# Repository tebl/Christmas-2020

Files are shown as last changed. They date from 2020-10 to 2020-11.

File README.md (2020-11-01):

# Christmas 2020
I wanted to do this project last year, but my health deteriorated and so the big Christmas 2019 project became the big Christmas 2020 project instead. 2020, if anything, provided plenty of time for sitting around the house thinking up how to make a blinking LED christmas tree with an Arduino Nano built into it! I even got around to adding a small video of it in action on [YouTube](https://www.youtube.com/watch?v=C256A0oTeUM)!

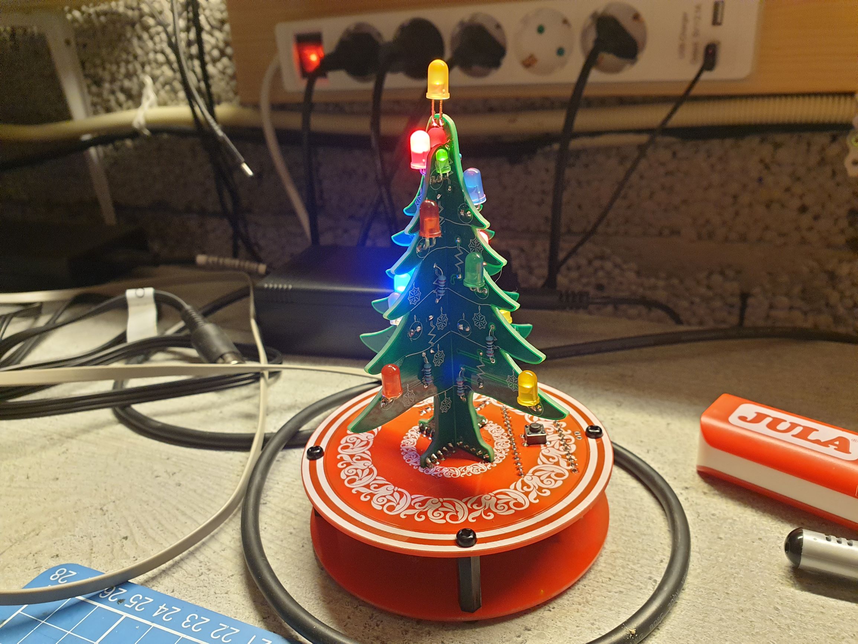
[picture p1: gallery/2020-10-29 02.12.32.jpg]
Christmas tree


The project is composed of three PCB designs, parts A/B are the actual tree and have been made so that they slot into eachother. Part C is the base, it holds the Arduino Nano and a couple of shift registers in addition to a switch that is used in order to toggle the various modes (I added a second Part C board to the bottom to add a little more weight).

As with any Christmas tree, you can decorate it with any LEDs though you might need to adjust the resistor values accordingly so that some of them aren't extremely bright (when in doubt, try them on a breadboard first). Alternatively - you could choose to skip the whole decorating step and put some string at the top and hang it from your tree (you will need to use some wire on the bottom to keep it from falling apart).

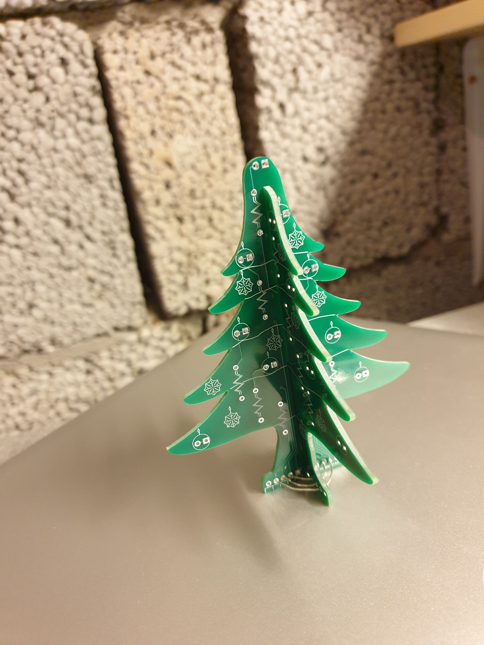
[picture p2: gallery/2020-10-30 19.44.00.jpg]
Bare christmas tree


## Building it
Start by examining all three PCBs, assuming you already have those handy - refer to the BOM below if you're wondering what parts to order from your favourite electronics boutique. Both of the A/B, the two tree parts should have a christmas bauble (at least I think that is the correct English translation of the round glass decorations) specifying both the part name (A or B) and wether you're looking at the front or the back. The latter details, the front and back bit, matters because this is the orientation it needs to be in when you want to slot it into the base (part C).

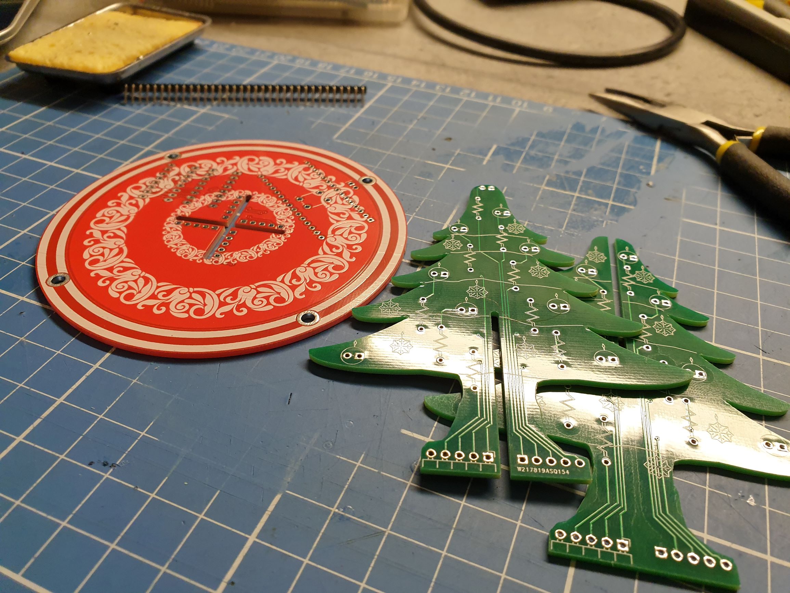
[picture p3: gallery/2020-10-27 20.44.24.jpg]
PCBs


Because I wanted something that looked good without any components, parts A/B will look different from the standard markings used for LEDs and resistors you would expect to encounter any other time of the year. The baubles with the two holes are for LEDs, you can solder them straight on or aim them upwards if you'd like to - feel free to use those weird LEDs you got as a gift (it's your tree after all) - the important bit is that the **square pad** is for the negative leg of the LED (the **shorter** one). The squiggly lines are for the resistors, you need to pick values that work with your LEDs, so test them in a breadboard first in order to figure out which value to use (or just put 100 Ohm for the dim ones, 330 for the normal LEDs and something like 1K for those bright ones like the blue). Try installing components so that every side gets something, at least that's what my parents always instruct me to do on the big plastic tree.

Parts A/B are attached to the base using right-angle pin headers, take care that you match the orientation to the corresponding parts on part C. While on the subject of part C, the only important part here is that you'll probably need to solder the switch into place before putting in the Arduino Nano (unless you'll be using female header pins so that you can remove it later). The rest of the components (including the Nano) will be installed on the underside of part C.

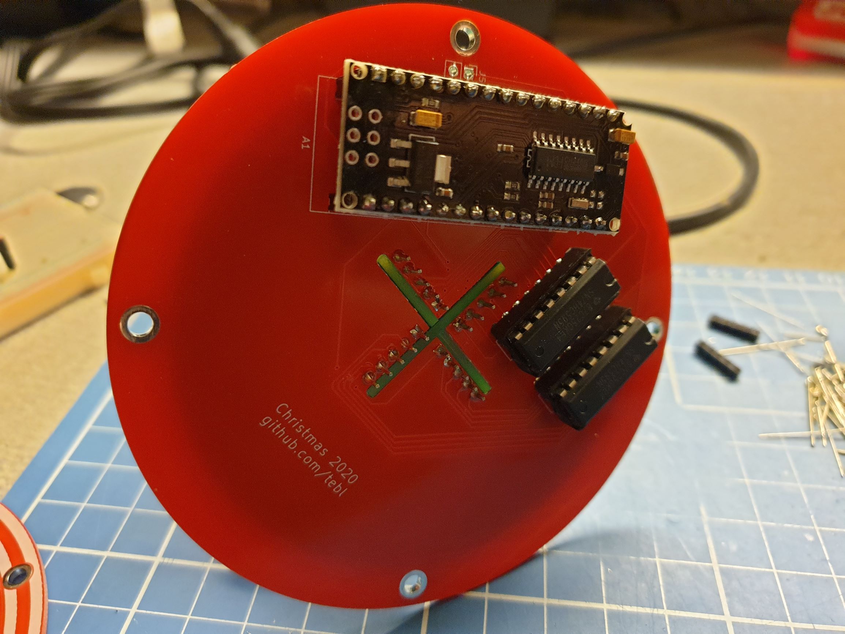
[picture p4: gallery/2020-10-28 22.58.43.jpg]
PCB component side


Given that there are components on the underside of the base, you'll need to add some M3 hex spacers to it so that it won't scrape against the table - if you have an extra part C PCB I recommend putting it on the bottom as well so that it doesn't get knocked around so easily.

## BOM
The BOM, or bill of manufacturing, is a list of the components used when constructing the complete christmas tree. Note that since you can substitute the LEDs/resistors you want to use - the following may be more of a suggestion though you'd need all of it in order to make everything blink. Most of these components should be easily obtainable through your favourite local electronics components store. Right-angle pin headers are usually sold in breakable strips with 40 pins, so just break off 5 pin segments where needed.

| Reference | Item | Count |
| --- | --- | ----- |
| Christmas A  | Fabricate using Gerber files ([order](https://www.pcbway.com/project/shareproject/Christmas_2020__part_A_.html)) | 1 |
| D1-D9 | LED (3mm or 5mm, colour as wanted) | 9 |
| R1-R9 | 220, 330 or 1k ohm resistor * | 9 |
| J1,J2 | 1x5-pin right-angle header | 2 |
| Christmas B  | Fabricate using Gerber files ([order](https://www.pcbway.com/project/shareproject/Christmas_2020__part_B_.html)) | 1 |
| D2-D9 | LED (3mm or 5mm, colour as wanted) | 8 |
| R2-R9 | 220, 330 or 1k ohm resistor * | 8 |
| J1,J2 | 1x5-pin right-angle header | 2 |
| Christmas C  | Fabricate using Gerber files ([order](https://www.pcbway.com/project/shareproject/Christmas_2020__part_C_.html)) | 1 |
| SW1 | SPST momentary push button | 1 |
| A1 | Arduino Nano | 1 |
| U1,U2 | 74HC595 (DIP-16) | 2 |
| | M3 nylon hex standoffs with screws | 4 |

*) Use resistors with values that would correspond to the LED you installed, use higher resistrance the brighter the LED (especially the blue ones). If a soldered in LED is too dim, install a lower value on the back as well in order to lower the resistance going to it.

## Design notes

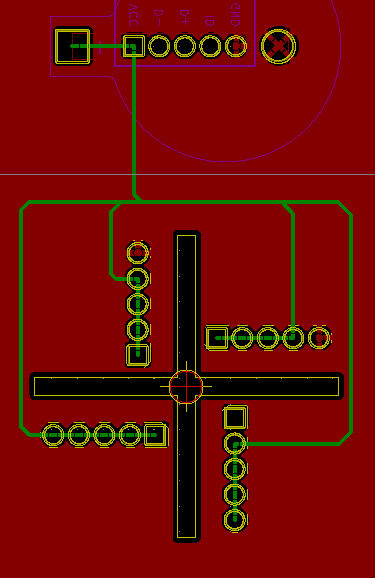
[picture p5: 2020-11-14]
gallery/Screenshot 2020-11-14 233453.png

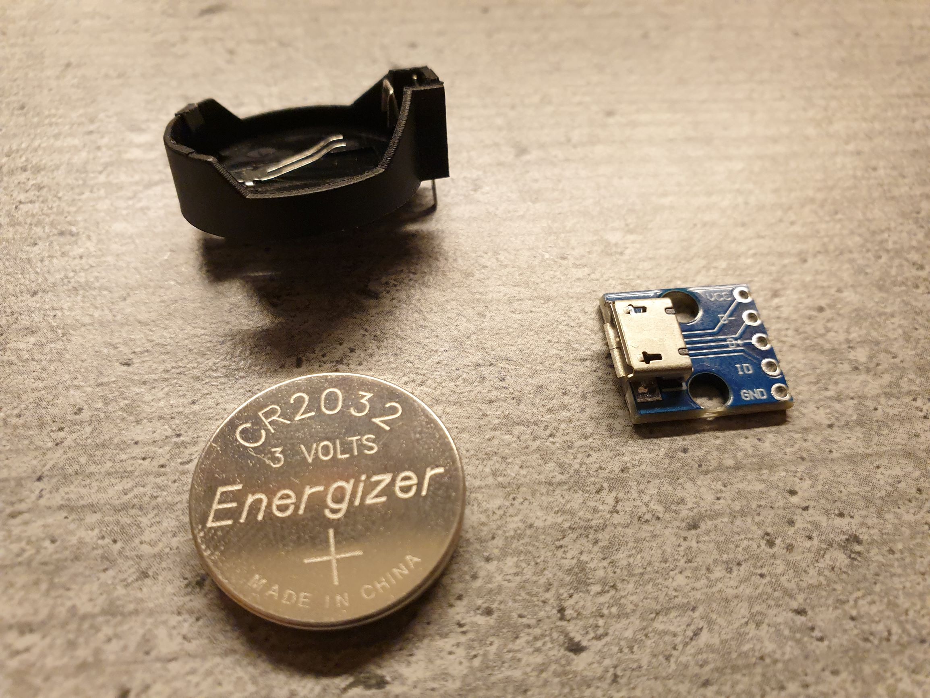
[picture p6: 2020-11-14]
gallery/2020-11-14 23.36.01.jpg

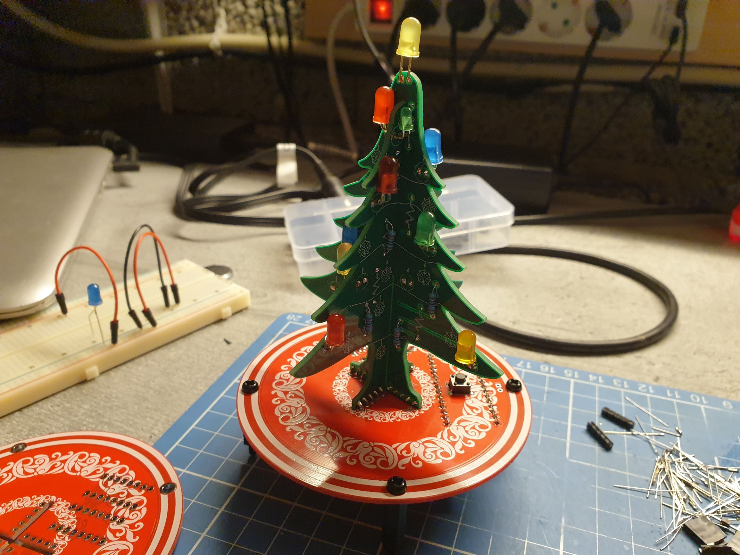
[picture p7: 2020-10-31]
gallery/2020-10-28 23.00.49.jpg

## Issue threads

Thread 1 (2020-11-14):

Request for an alternate version

Treearecool, 2020-11-14:
Hello,

I really like how the tree looks and works, but i am reluctant to create multiple of them to gift them out to my friends and family. Is it possible that you can create a battery powered version of the Part C board, perhaps with a CR2032-BS-5-1 connector, that simply powers the tree, without it blinking? It could keep costs down and would still look good as a gift.

Thanks!

tebl, 2020-11-14:
If you already have part C, then you could do that with a few wires though I realize that might scare most that aren't used to DIY projects (see https://github.com/tebl/Christmas-2020/raw/main/gallery/Screenshot%202020-11-14%20233453.png for example). I threw together a part C2 like you described - could not use the part you specified as I do not have it, also it is meant to be installed vertically instead of flat on a board. Did an option for the generic black flat chinese CR2032 holder instead as well as a MicroUSB breakout module (see https://github.com/tebl/Christmas-2020/raw/main/gallery/2020-11-14%2023.36.01.jpg for picture).

Treearecool, 2020-11-15:
Thank You Very Much.

Closed 2020-11-15.

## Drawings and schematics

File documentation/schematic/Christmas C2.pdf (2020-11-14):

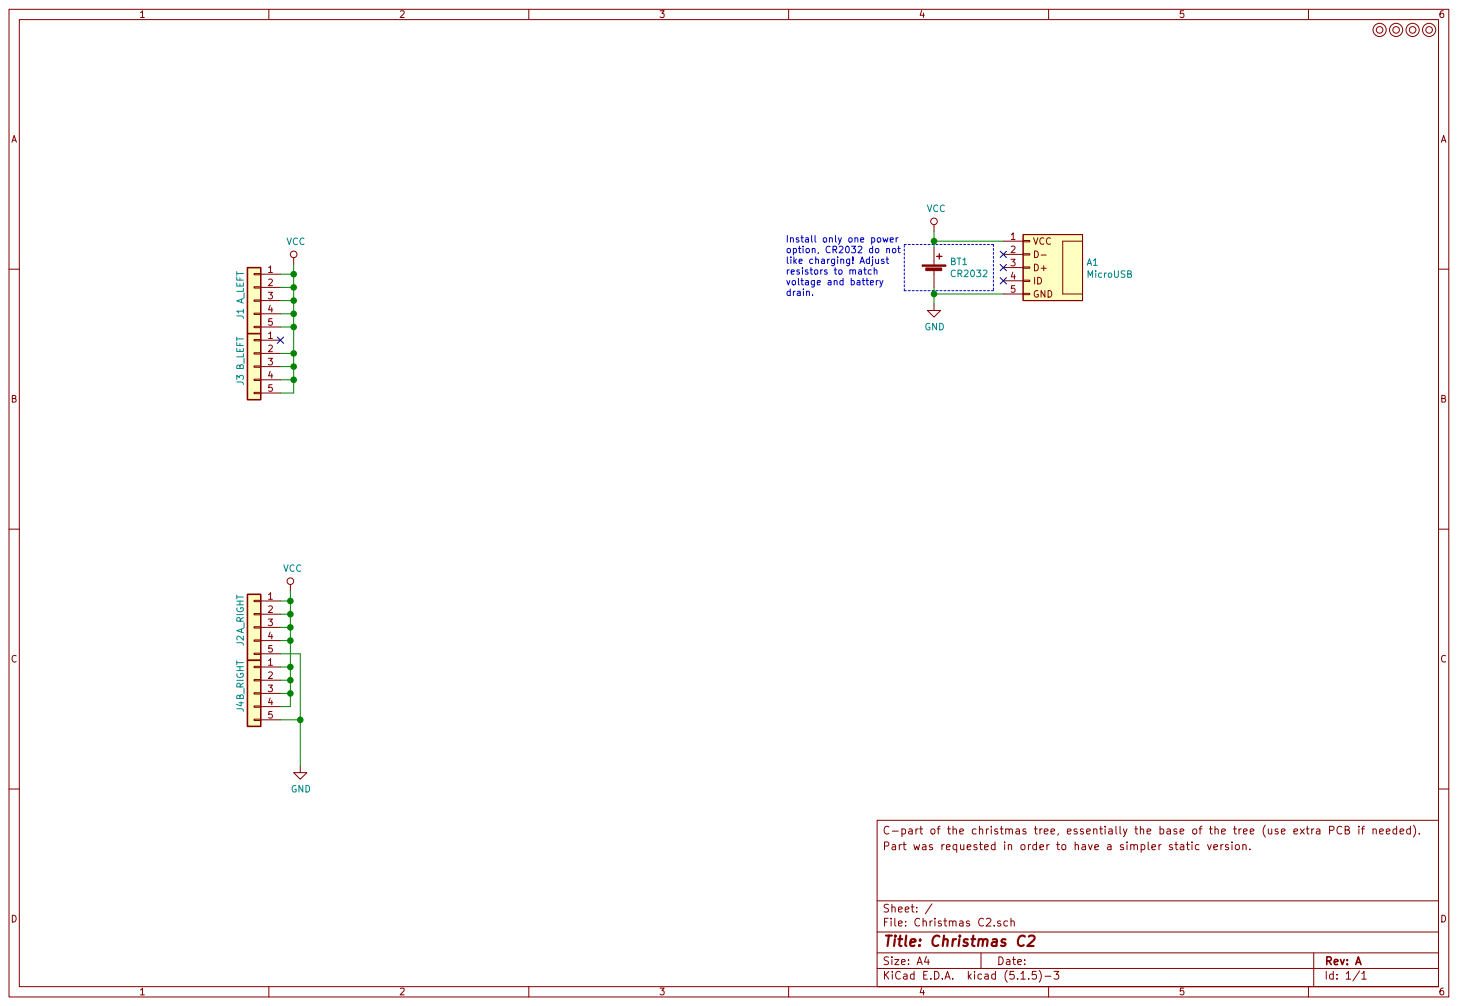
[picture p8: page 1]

Install only one power
option, CR2032 do not
like charging! Adjust resistors to match voltage and battery drain.

C-part of the christmas tree, essentially the base of the tree (use extra PCB if needed).
File: Christmas C2.sch Sheet: / Part was requested in order to have a simpler static version.

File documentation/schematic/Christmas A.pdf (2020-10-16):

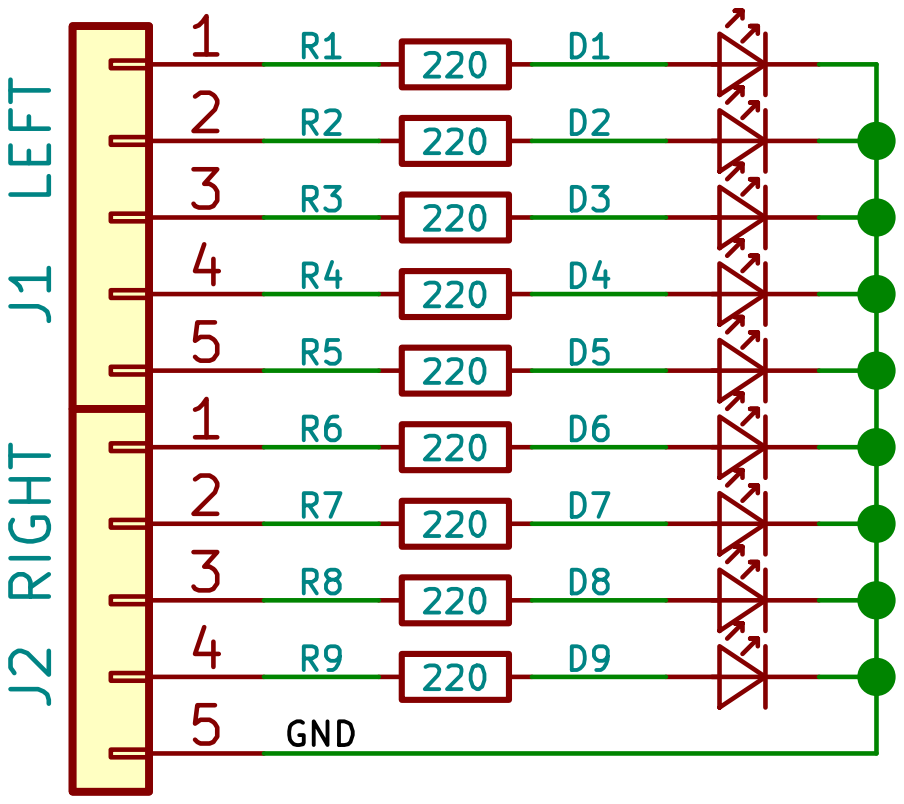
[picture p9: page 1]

File: Christmas A.sch Sheet: / Slot into B-side before soldering star into place. A-side of the christmas tree.

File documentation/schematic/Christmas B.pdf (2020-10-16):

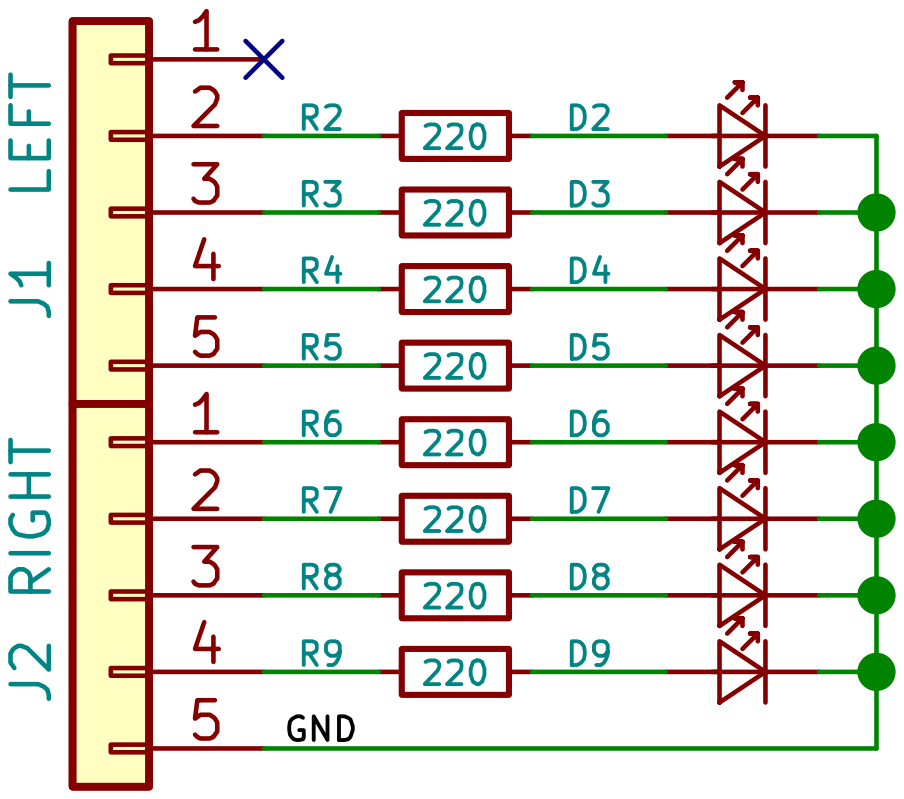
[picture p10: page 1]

File: Christmas B.sch Sheet: / Slot into A-side before soldering star into place. B-side of the christmas tree.

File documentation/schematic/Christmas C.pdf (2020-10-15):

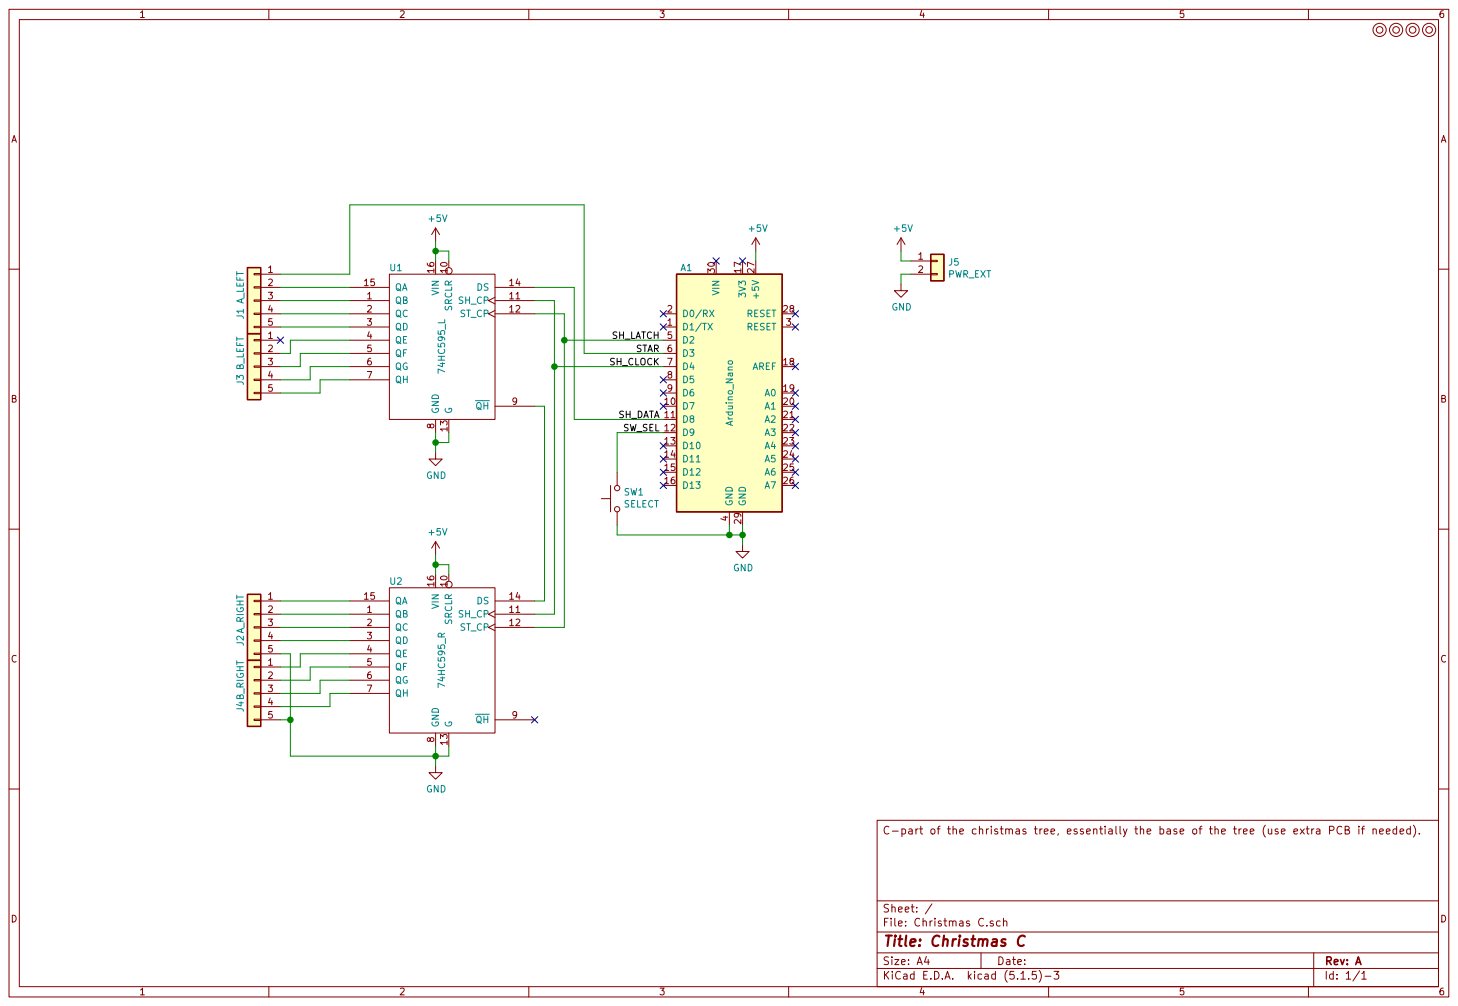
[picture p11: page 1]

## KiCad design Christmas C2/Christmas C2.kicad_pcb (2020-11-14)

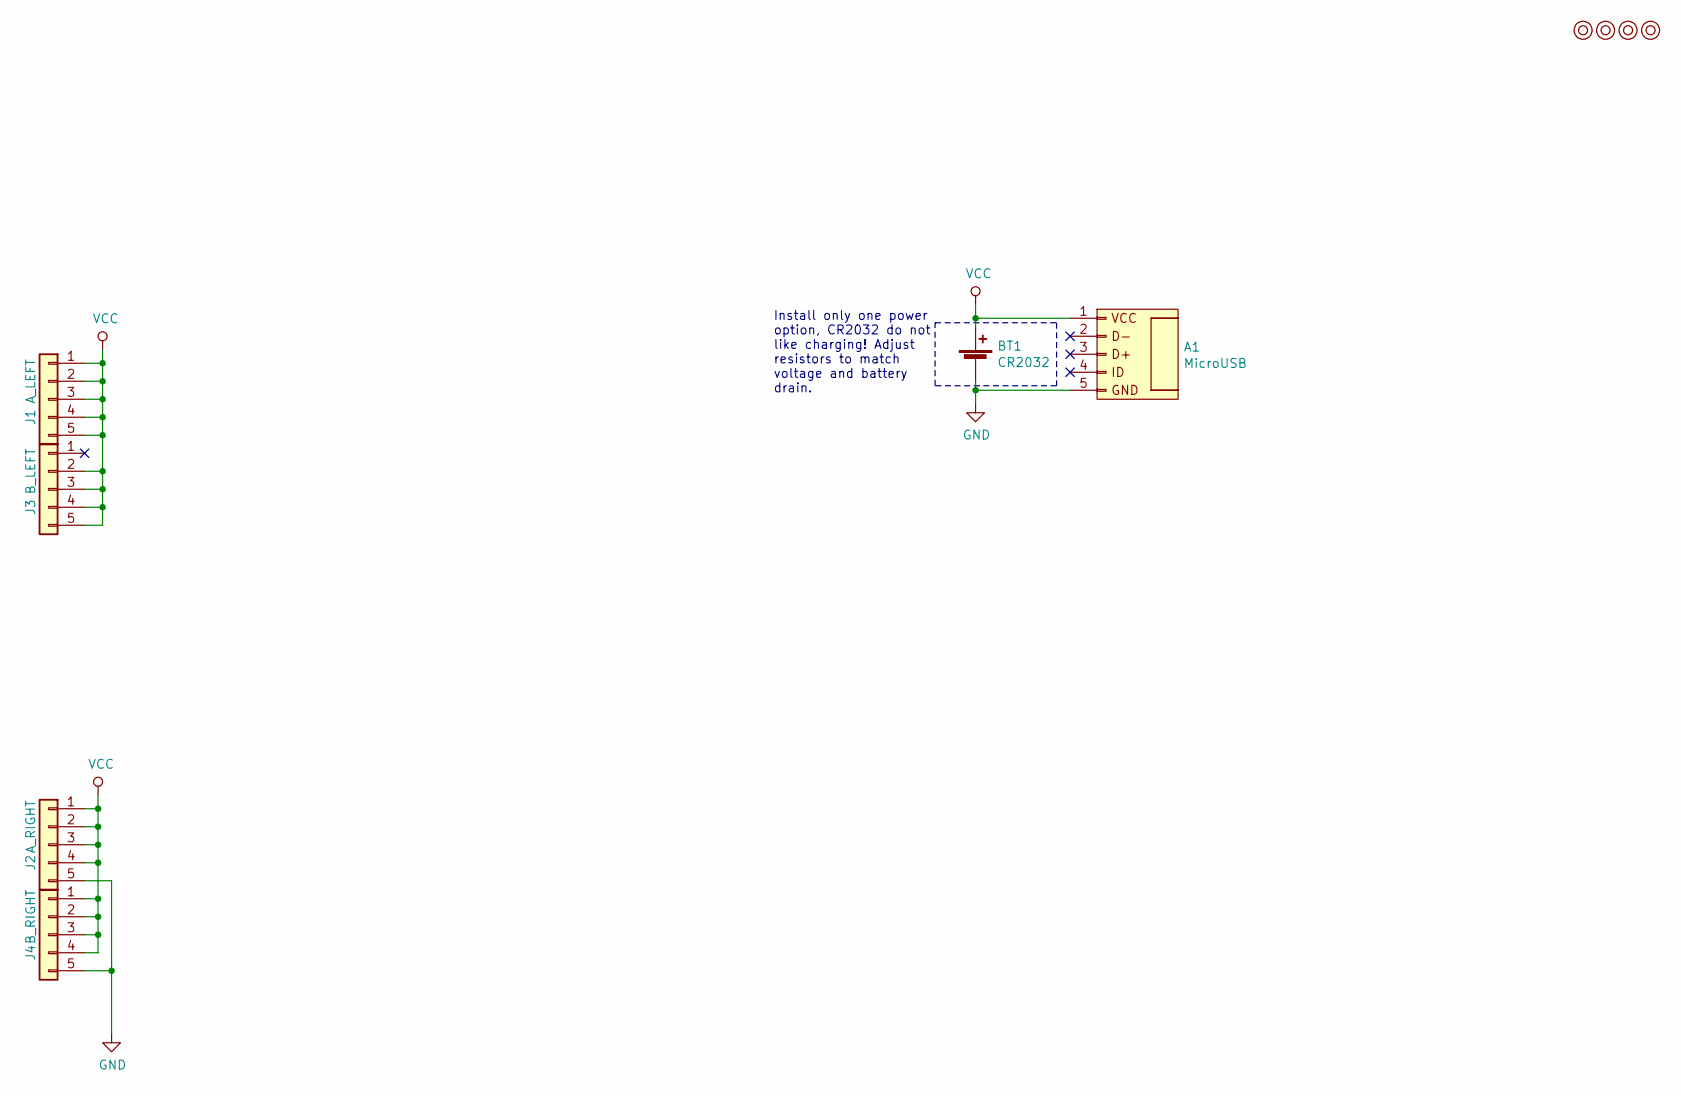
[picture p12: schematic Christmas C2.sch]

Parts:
A1: MicroUSB; microusb_breakout
BT1: CR2032; Keystone_103_1x20mm-CoinCell
J1: A_LEFT; conn_base
J2: A_RIGHT; conn_base
J3: B_LEFT; conn_base
J4: B_RIGHT; conn_base
M1, M2, M3, M4: Mounting; M3

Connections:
GND: A1.5 (GND), BT1.2 (-), J2.5, J4.5
VCC: A1.1 (VCC), BT1.1 (+), J1.1, J1.2, J1.3, J1.4, J1.5, J2.1, J2.2, J2.3, J2.4, J3.2, J3.3, J3.4, J3.5, J4.1, J4.2, J4.3, J4.4

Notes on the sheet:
Install only one power option, CR2032 do not like charging! Adjust resistors to match voltage and battery drain.

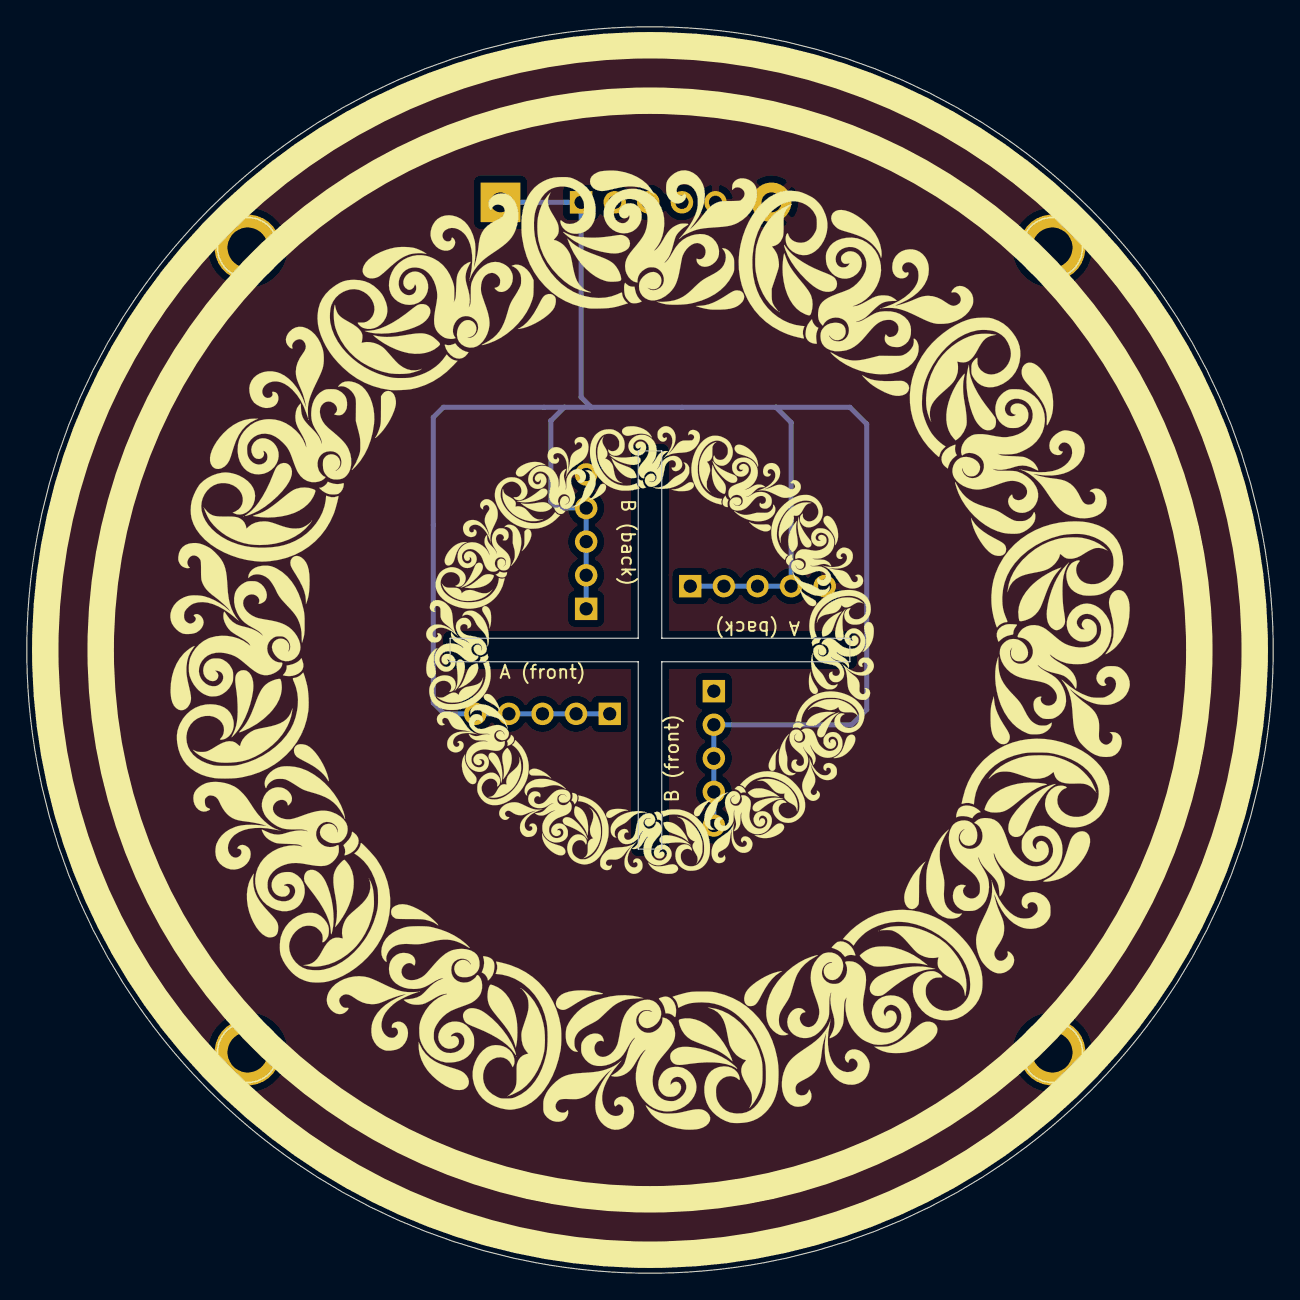
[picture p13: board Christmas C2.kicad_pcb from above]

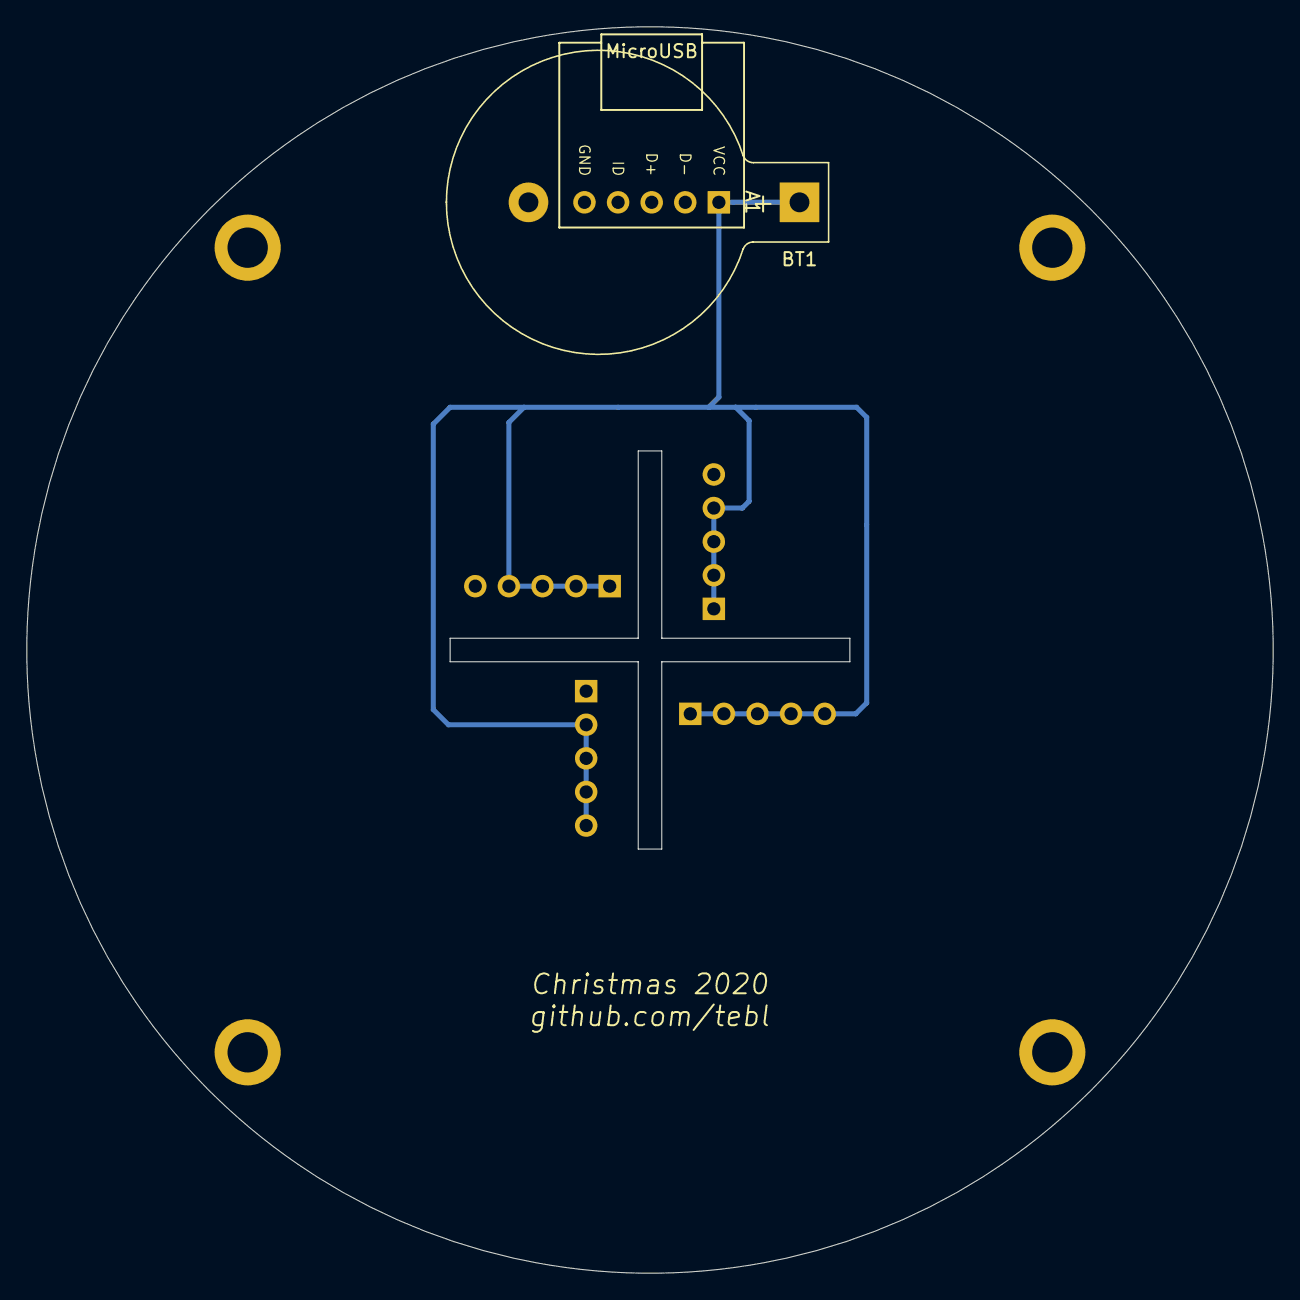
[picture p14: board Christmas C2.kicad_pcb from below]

Board: 2 copper layers, 94.2 x 94.2 mm, 10 parts (2 on the bottom side), 2 nets.

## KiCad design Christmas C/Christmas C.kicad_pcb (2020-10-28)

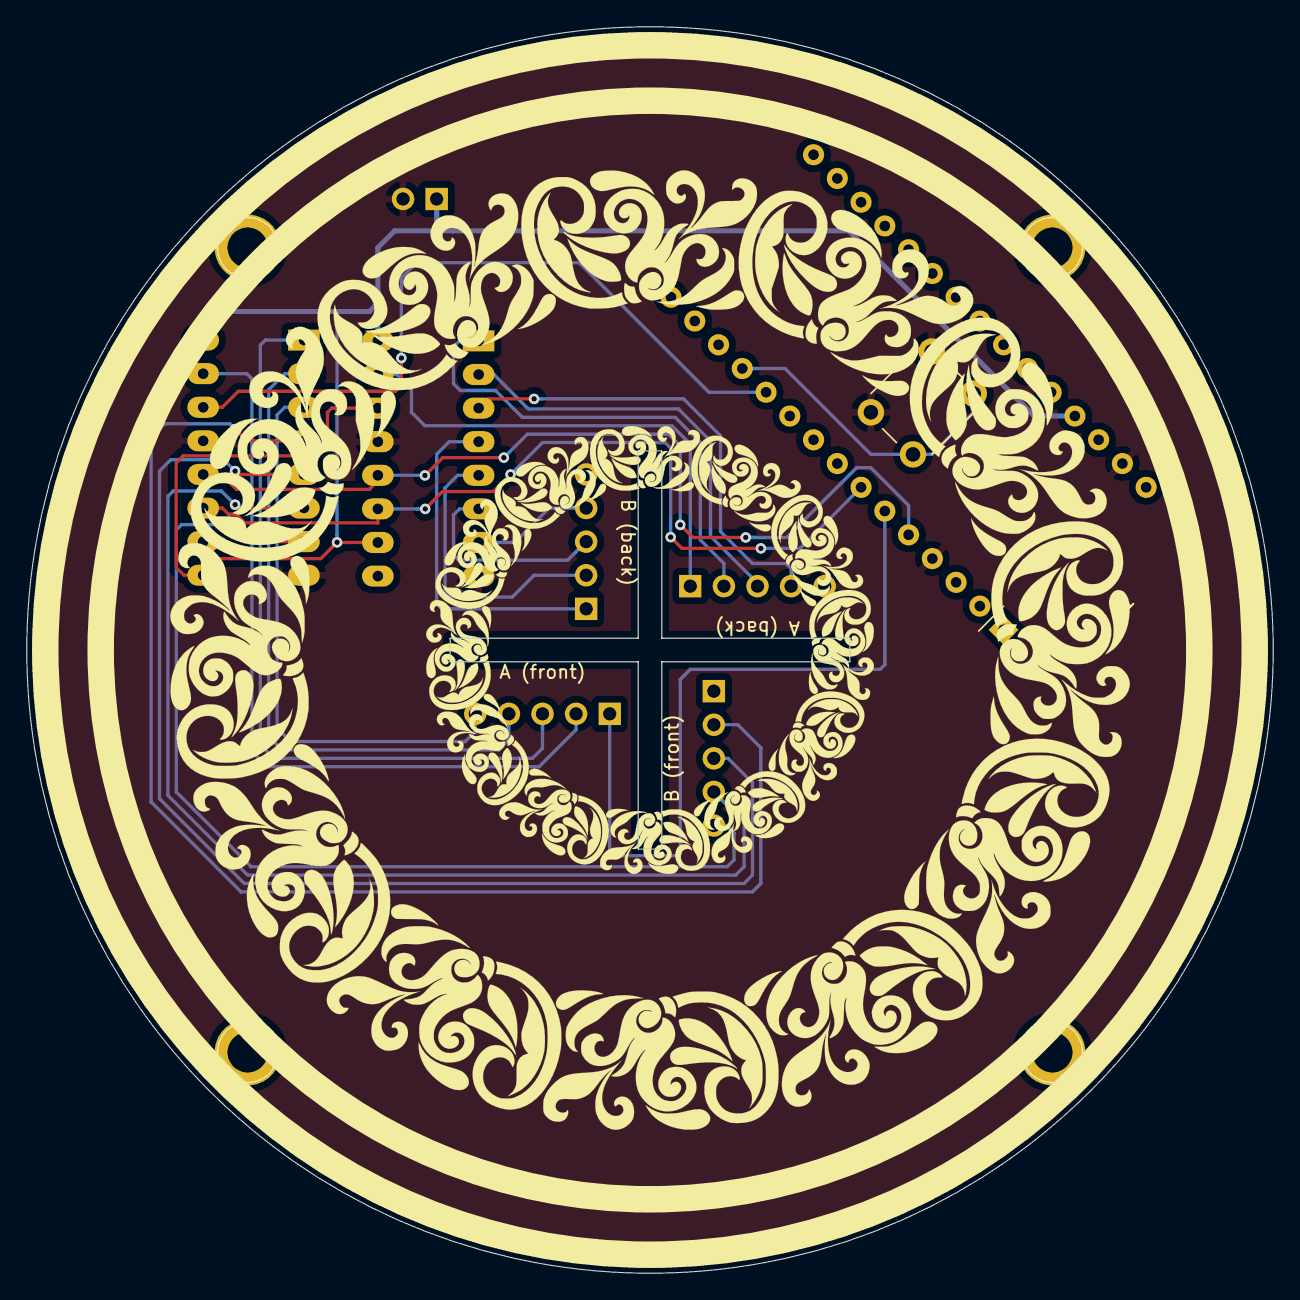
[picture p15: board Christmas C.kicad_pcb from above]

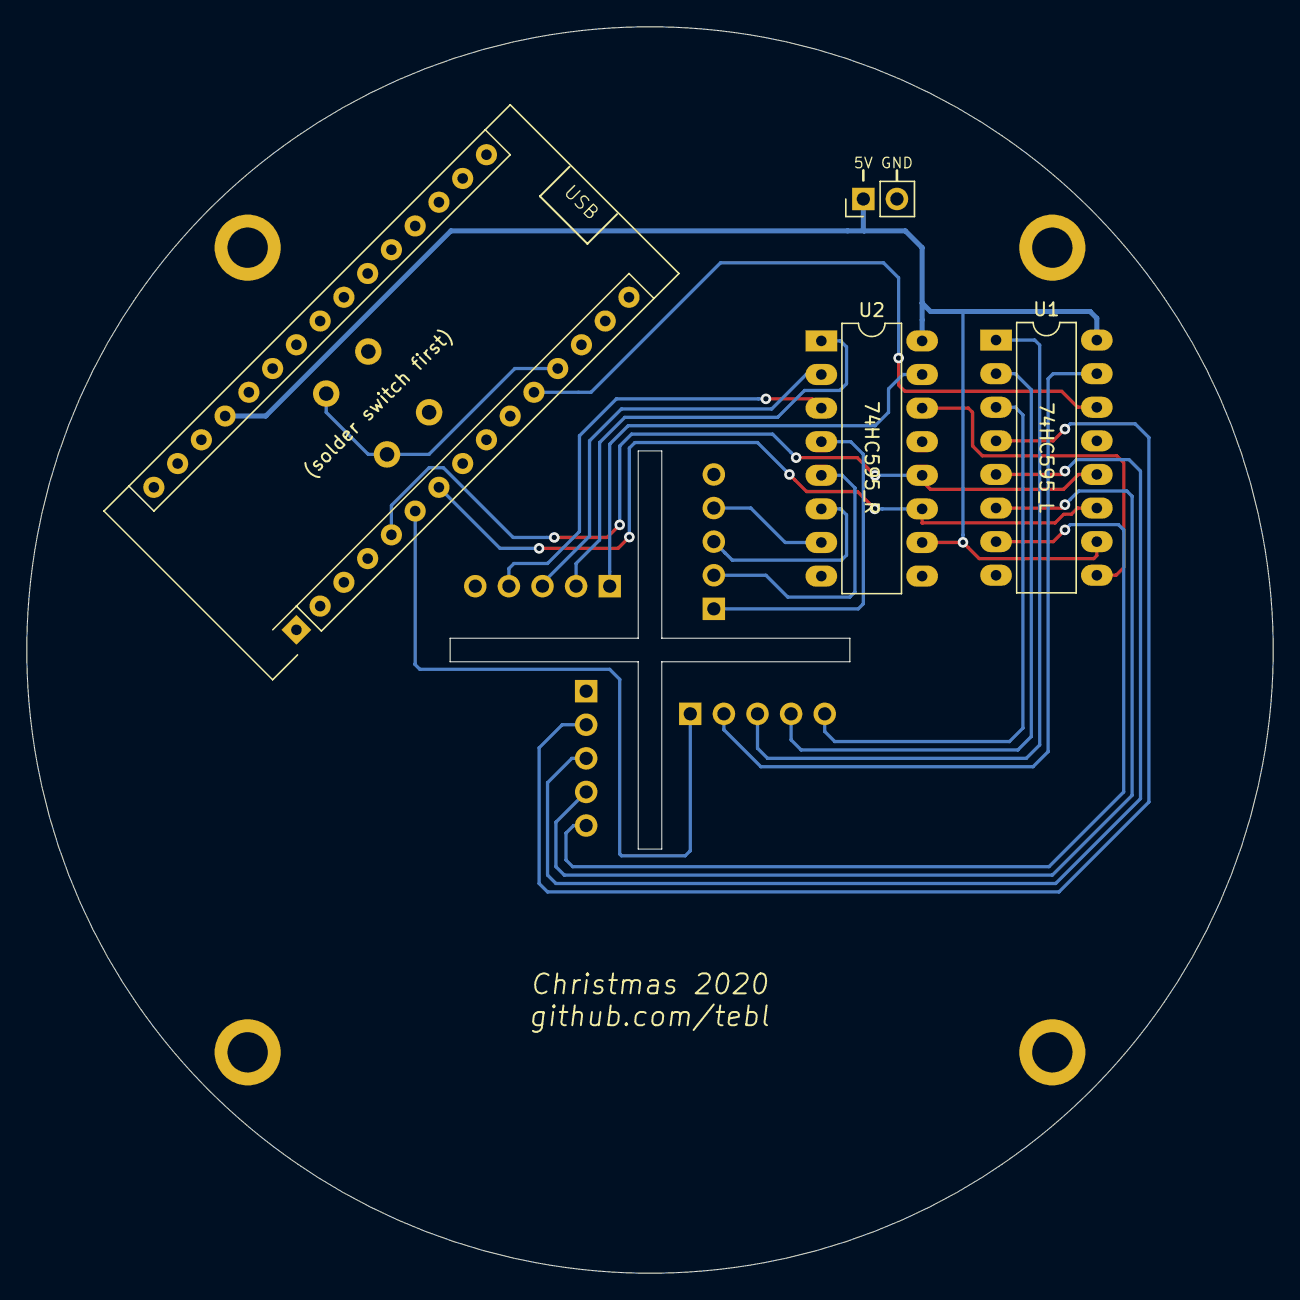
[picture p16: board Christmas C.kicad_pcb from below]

Board: 2 copper layers, 94.2 x 94.2 mm, 13 parts (4 on the bottom side), 24 nets.

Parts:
A1: Arduino_Nano
J1: A_LEFT; conn_base
J2: A_RIGHT; conn_base
J3: B_LEFT; conn_base
J4: B_RIGHT; conn_base
J5: PWR_EXT; Pin_Header_Straight_1x02_Pitch2.54mm
M1, M2, M3, M4: Mounting; M3
SW1: SELECT; SW_PUSH_6mm
U1: 74HC595_L; DIP-16_W7.62mm_LongPads
U2: 74HC595_R; DIP-16_W7.62mm_LongPads

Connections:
+5V: A1.27, J5.1, U1.10, U1.16, U2.10, U2.16
/SH_CLOCK: A1.7, U1.11, U2.11
/SH_DATA: A1.11, U1.14
/SH_LATCH: A1.5, U1.12, U2.12
/STAR: A1.6, J1.1
/SW_SEL: A1.12, SW1.2
GND: A1.4, A1.29, J2.5, J4.5, J5.2, SW1.1, U1.8, U1.13, U2.8, U2.13
unnamed: J1.2, U1.15
unnamed: J1.3, U1.1
unnamed: J1.4, U1.2
unnamed: J1.5, U1.3
unnamed: J2.1, U2.15
unnamed: J2.2, U2.1
unnamed: J2.3, U2.2
unnamed: J2.4, U2.3
unnamed: J3.2, U1.4
unnamed: J3.3, U1.5
unnamed: J3.4, U1.6
unnamed: J3.5, U1.7
unnamed: J4.1, U2.4
unnamed: J4.2, U2.5
unnamed: J4.3, U2.6
unnamed: J4.4, U2.7
unnamed: U1.9, U2.14

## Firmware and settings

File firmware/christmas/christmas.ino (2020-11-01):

#define BAUD_RATE 115200

#define SHIFT_DATA 8
#define SHIFT_CLOCK 4
#define SHIFT_LATCH 2
#define SW_MODE 9
#define LED_STAR 3
#define LED_STAR_MIN 8
#define LED_STAR_MAX 64
#define LED_STAR_INCREMENT 10

#define MODE_FALLING 0
#define MODE_GROWING 1
#define MODE_RANDOM 2
#define MODE_FADE 3
#define MODE_MAX 3

int mode = -1;
byte star_value = 0;
bool star_fading_out = false;
unsigned long time_next = 0;

void setup() {
  Serial.begin(BAUD_RATE);
  pinMode(LED_STAR, OUTPUT);
  pinMode(SHIFT_DATA, OUTPUT);
  pinMode(SHIFT_CLOCK, OUTPUT);
  pinMode(SHIFT_LATCH, OUTPUT);
  pinMode(SW_MODE, INPUT_PULLUP);

  next_mode();
}

/*
 * Sets the LEDs according to the supplied parameters.
 */
void set_values(byte star, byte data_a, byte data_b) {
  if (star_value != star) {
    analogWrite(LED_STAR, star);
    star_value = star;
  }
  shiftOut(SHIFT_DATA, SHIFT_CLOCK, MSBFIRST, data_b);
  shiftOut(SHIFT_DATA, SHIFT_CLOCK, MSBFIRST, data_a);
  digitalWrite(SHIFT_LATCH, LOW);
  digitalWrite(SHIFT_LATCH, HIGH);
  digitalWrite(SHIFT_LATCH, LOW);
}

/*
 * Handles fading the LED at the top of the christmas tree.
 */
int fade_star() {
  int value = star_value;

  if (star_fading_out) {
    value -= LED_STAR_INCREMENT;
    if (value < LED_STAR_MIN) {
      star_fading_out = false;
      value = LED_STAR_MIN;
    }
    return value;
  } else {
    value += LED_STAR_INCREMENT;
    if (value > LED_STAR_MAX) {
      star_fading_out = true;
      value = LED_STAR_MAX;
    }
    return value;
  }
}

/*
 * Debounces the mode select switch, calls a function to next_mode
 * function in order to actually change mode.
 */
bool old_switch_state = HIGH;
bool new_switch_state1 = HIGH;
bool new_switch_state2 = HIGH;
bool new_switch_state3 = HIGH;
void handle_switch() {
  new_switch_state1 = digitalRead(SW_MODE); delay(1);
  new_switch_state2 = digitalRead(SW_MODE); delay(1);
  new_switch_state3 = digitalRead(SW_MODE);

  if ((new_switch_state1 == new_switch_state2) && (new_switch_state1 == new_switch_state3)) {
    if (new_switch_state1 != old_switch_state) {
      if (new_switch_state1 == LOW) {
        next_mode();
      }
    }
    
    old_switch_state = new_switch_state1;
  }
}

/*
 * Switch LED mode to the next one, note that in the case of
 * the first run (current mode is -1) we always initialize to
 * the first one.
 */
void next_mode() {
  set_values(0, 0, 0);

  if (mode == -1) {
    set_mode(0);
  } else {
    mode += 1;
    if (mode > MODE_MAX) mode = 0;
  
    set_values(0, 1 << mode, 1 << mode);
    time_next = millis() + 3000;
    set_mode(mode);
  }
}

/*
 * Called when the mode should be set to something specific. Not much
 * here, but in case any later added modes needs implicit initialization
 * then this would be where to put it.
 */
void set_mode(int number) {
  mode = number;
  Serial.print("Mode set to ");
  switch(mode) {
    case MODE_FALLING: Serial.println("FALLING"); break;
    case MODE_GROWING: Serial.println("GROWING"); break;
    case MODE_RANDOM: Serial.println("RANDOM"); break;
    case MODE_FADE: Serial.println("FADE"); break;
    default: Serial.println("UNKNOWN"); break;
  }
}

/*
 * Called from the main loop. Keeps track of the current time, when
 * it is time to perform a step we proxy the call to the function
 * specific to each mode.
 */
void handle_mode() {
  if (millis() > time_next) {
    switch(mode) {
      case MODE_FALLING: do_step_falling(); break;
      case MODE_GROWING: do_step_growing(); break;
      case MODE_RANDOM: do_step_random(); break;
      case MODE_FADE: do_step_fade_star(); break;
    }
  }

  // In case we forgot to schedule next step...
  if (millis() > time_next) time_next = millis() + 1000;
}

/*
 * LED mode that should start by lighting a set of LEDs at the top
 * of the tree, then those LEDs "fall" toward the bottom of the tree.
 * 
 * Star will be fading with each step.
 */
byte mode_falling_value = 0x00;
void do_step_falling() {
  if (mode_falling_value == 0x00) mode_falling_value = 0x01;
  else mode_falling_value = mode_falling_value << 1;
  set_values(fade_star(), mode_falling_value, mode_falling_value);
}

/*
 * LED mode that starts by lighting LEDs at the top, then starts
 * lighting all of the LEDs toward the bottom until everything is
 * lit up.
 * 
 * Star will be fading with each step.
 */
byte mode_growing_value = 0;
void do_step_growing() {
  byte value = 1;

  if (mode_growing_value == 0) {
    mode_growing_value++;
    value = 0;
  } else {
    for(int i = 0; i < mode_growing_value; i++) {
      value = value << 1;
      value += 1;
    }
    
    mode_growing_value++;
    if (mode_growing_value > 8) mode_growing_value = 0;
  }

  set_values(fade_star(), value, value);
  time_next = millis() + 1000;
}

/*
 * A randomized LED mode that for every step, will 40% of the time attempt
 * to either lit or extinguish a random LED (depending on the current value).
 * 
 * Star will be fading with each step.
 */
byte mode_random_value_a = 0x00;
byte mode_random_value_b = 0x00;
void do_step_random() {
  switch(random(0, 6)) {
    case 0: mode_random_value_a = randomize_bit(mode_random_value_a); break;
    case 1: mode_random_value_b = randomize_bit(mode_random_value_b); break;
    default: break;
  }
  
  set_values(fade_star(), mode_random_value_a, mode_random_value_b);
  time_next = millis() + 250;
}

/*
 * Takes a the supplied byte and then randomly flip one of the 8 bits.
 */
byte randomize_bit(byte current) {
  byte bit_num = random(0, 8);
  if (bitRead(current, bit_num) == 0) return bitSet(current, bit_num);
  return bitClear(current, bit_num);
}

/*
 * LED mode where the tree itself is dark, but we'll fade the star in
 * and out. The background for this is a local tradition where the tree
 * isn't lit until the day before christmas eve, but the star is there
 * to guide the way.
 */
void do_step_fade_star() {
  set_values(fade_star(), 0, 0);
  time_next = millis() + 200;
}

/*
 * Main loop.
 */
void loop() {
  handle_switch();
  handle_mode();
}

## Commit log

2020-10-14 Basic tree
    [Christmas A.kicad_pcb, Christmas A.sch]
2020-10-14 Mirror components
    [Christmas A.kicad_pcb]
2020-10-14 Stars added
    [Christmas A.kicad_pcb]
2020-10-15 Changed the top
    [Christmas A.kicad_pcb, Christmas A.sch]
2020-10-15 Added B side
    [Christmas A.sch, Christmas B.kicad_pcb, Christmas B.sch]
2020-10-15 Make space at the bottom
    [Christmas A.kicad_pcb, Christmas B.kicad_pcb]
2020-10-15 Added base
    [Christmas C.kicad_pcb, Christmas C.sch]
2020-10-16 Gerber export
    [Christmas A-B_Cu.gbl, Christmas A-B_Mask.gbs, Christmas A-B_Paste.gbp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]
2020-10-27 Tweaked bottom connectors
    [Christmas C.kicad_pcb]
2020-10-28 Changed Nano footprint to something standard
    [Christmas C.kicad_pcb]
2020-10-28 Added markings to part A
    [Christmas A.kicad_pcb]
2020-10-28 Added part designation to A/B
    [Christmas B.kicad_pcb]
2020-10-29 Added arduino sketch
2020-10-31 Updated gerbers
    [Christmas A-B_Cu.gbl, Christmas A-B_Mask.gbs, Christmas A-B_Paste.gbp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]
2020-11-01 Added BOM
2020-11-01 Added PCB links for PCBway
2020-11-14 Static version of part C
    [Christmas C2-B_Cu.gbl, Christmas C2-B_Mask.gbs, Christmas C2-B_Paste.gbp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]
2020-11-14 Added MicroUSB breakout adapter and battery option to static board
    [Christmas C2-B_Cu.gbl, Christmas C2-B_Mask.gbs, Christmas C2-B_Paste.gbp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]
